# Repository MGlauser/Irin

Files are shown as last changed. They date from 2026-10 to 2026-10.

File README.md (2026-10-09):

# Irin

**The wakeful one: an always-on battery watcher for Home Assistant.**

Irin is an always-on battery monitor that clamps onto a battery's terminals and reports
**voltage, state of charge (SOC), charging activity and temperature** to
[Home Assistant](https://www.home-assistant.io/) over WiFi, with a tiny OLED readout on
the device itself.

The prototype watches the 12V accessory battery of a 2027 Subaru Uncharted GT (an EV whose
12V battery can run down in a couple of days of parking), but nothing in it is
car-specific. Change a few lines of configuration and it monitors **flooded lead-acid,
AGM, LiFePO4 or sodium-ion** batteries in **12V, 24V or 48V** systems: RVs and boats,
ham radio go-boxes and repeater power, solar and home backup banks, golf carts, stored
vehicles.

No cloud, no vehicle telematics, no OBD dongle: one ESP32 board on the battery, one
entry in your Home Assistant.

<p align="center">
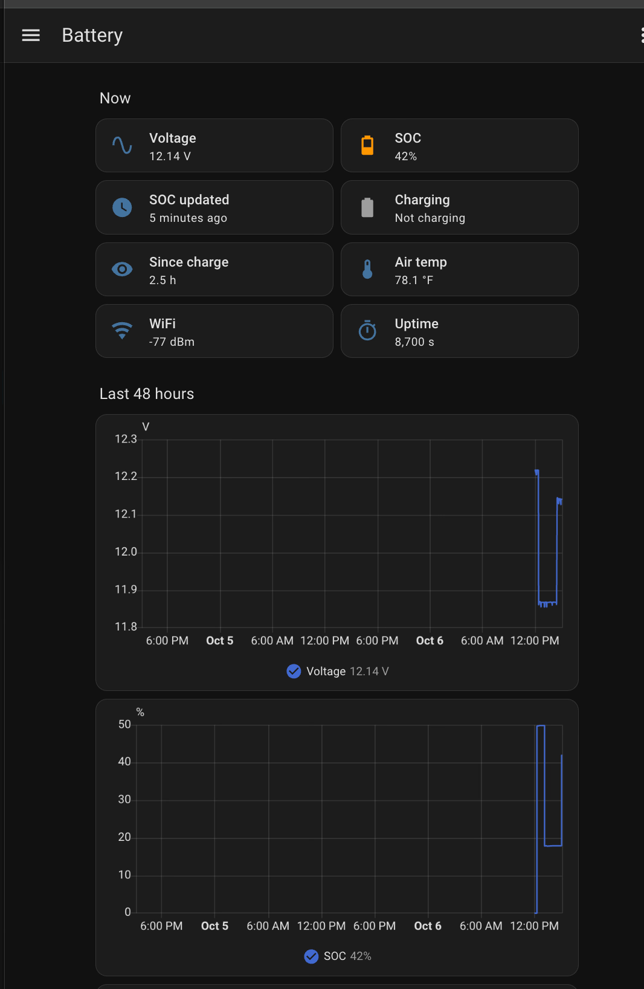
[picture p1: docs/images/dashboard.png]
Irin dashboard in Home Assistant: voltage, SOC, charging status and 48-hour history
  
</p>
<p align="center"><sub>The included dashboard on the bench prototype. SOC steps only
after a rest window (0% from an early reboot loop, then 50%, ~17% and 42% as the bench
supply was changed); voltage is charted continuously. And 42% is, of course, the
answer.</sub></p>

### The name

*Irin* (Aramaic עִירִין, *ʿirin*; singular *ʿir*) means "watchers", literally "the
wakeful ones": those who do not sleep. It is the word for the Watchers of the Book of
Enoch, whose first part (1 Enoch 1–36) is called *The Book of the Watchers* and survives
in Aramaic among the Dead Sea Scrolls. The same word appears in Daniel 4:13: "a watcher
and a holy one came down from heaven."

The name is meant in the sense of the *holy* Watchers, the ones who kept their post
(1 Enoch 20 names them: Uriel, Raphael, Raguel, Michael, Saraqael, Gabriel and Remiel),
not the fallen ones the book is better known for.

It is also the design in one word. Deep sleep was evaluated and rejected (on the
prototype it would buy about 2% more runway), so the monitor stays awake around the
clock, watching the battery so you don't have to.

---

## What it does

| | |
|---|---|
| **Voltage** | Measured every 30 s with a 16-bit ADC (0.7 mV resolution at 12V) and published continuously, never gated. Charts charging cycles in detail. |
| **State of charge** | Looked up from *resting* voltage, temperature-corrected, and only updated when the battery has truly rested (see below). Holds its last good value otherwise, with a "last updated" timestamp. |
| **Charging** | On/off, detected from voltage with hysteresis, plus *Time Since Charging*. Shows whether the charging source (alternator, DC-DC converter, solar, shore power) is actually doing its job. |
| **Away report** | While Home Assistant is unreachable (the car is away from home WiFi, or HA is down), the device keeps a summary: lowest voltage, lowest SOC, time below the alert level, charging time and events. Published when it reconnects, e.g. *"3.2 d: SOC min 46%, 4.0 h below 50%, 6 charges"*. Gaps under 30 minutes are ignored. |
| **Temperature / humidity** | DHT22 sensor, used for the SOC temperature correction. |
| **On-device display** | Voltage, SOC, temperature and rest/charging status on a 72×40 OLED. Blanks after 2 minutes to prevent burn-in; the BOOT button wakes it. Stays lit while charging. |
| **Home Assistant** | Native ESPHome integration (no MQTT broker), a ready-made dashboard, and history for long-term battery-health trends. Alerts are ordinary HA automations. |

It draws about **10 mA at 12V** on WiFi, and about **40 mA** while out of WiFi range with
its fallback network up (see [Fallback WiFi network](#fallback-wifi-network-and-its-power-cost)).

### Why SOC needs a "rest gate"

A battery's voltage only tells you its state of charge when it has been sitting
unloaded and uncharged for a while. During and after charging it reads high (surface
charge), so a naive voltage-to-SOC lookup reports 100% on a battery that may be
failing, and a low-battery alert fires late or never.

So SOC is recomputed only after the voltage has stayed below the charging threshold for
**30 minutes** *and* has been stable (within 5 mV per 5 minutes) for **15 minutes**.
Voltage itself is never gated: you always see the raw trace.

---

## Hardware

| Part | Notes |
|---|---|
| **01Space ESP32-C3-0.42LCD** ("ESP32-C3 SuperMini 0.42 OLED") | ESP32-C3 with a built-in 72×40 SSD1306 OLED. I2C on SDA=GPIO5 / SCL=GPIO6 (verified). |
| **ADS1115** 16-bit ADC module (e.g. HiLetgo) | I2C at 0x48 (ADDR→GND), powered from 3.3V. Battery on A0 through the divider. |
| **Voltage divider** R1/R2, 1% metal film, same series | 47k / 10k for 12V systems (see the voltage table for 24/48V). |
| **C1**, 2 nF across R2 | 2× 1000 pF mica in parallel (low leakage). |
| **MP1584EN** buck module, set to 5.0V | Feeds the board's 5V pin. 12V systems only; see 24/48V below. |
| **DHT22 / AM2302** + 3-pin JST-XH (J2) | Best outside the enclosure (cable ≤1 m at 3.3V); inside works, reading a few °C warm, which errs toward an early alert. |
| **Fuse** at the battery positive terminal | 5 A, DC-rated for the system voltage. Protects the wiring, not the 10 mA load. |
| **TVS diode** D1 | P6KE18A for 12V. Fitted as standard: it clamps switching transients, and a reversed hookup forward-biases it and blows the fuse. |
| **Enclosure** | 3D printed, PETG or ASA. |

- Full bill of materials, wiring and divider math: [`PARTS.md`](PARTS.md).
- Schematic: [`hardware/`](hardware/) (KiCad 10), PDF preview in
  [`hardware/preview.pdf`](hardware/preview.pdf).
- Breadboard layout for a 400-point board: open
  [`hardware/breadboard/breadboard.html`](hardware/breadboard/breadboard.html) in a
  browser. It is generated and checked against the schematic's netlist by
  `make_breadboard.py`.

### The one wiring rule that matters

**R2 and C1 must return to the ADS1115's own GND pin, and that ground must meet power
ground at exactly one point.** If the divider and the ADC sit on different ground paths,
the supply current's voltage drop appears in series with the measurement and gets
multiplied by the divider ratio. On the prototype, 15 mV of ground drop between two
breadboard rails became an 86 mV error at the battery, and it drifted.
This applies to wired builds. On the PCB, the solid GND plane does the same job and R2/C1
connect to it directly.

---

## Build and install

### 1. Bench build
1. Set the buck module to **5.0V** before connecting it to anything.
2. Build the circuit (breadboard first is a good idea; see the layout above).
3. Power from a bench supply. Check that the OLED lights up and both I2C devices appear
   in the ESPHome log (0x3C and 0x48).

### 2. Firmware (ESPHome)
The firmware is a single ESPHome config: [`esphome/irin.yaml`](esphome/irin.yaml).

**With the Home Assistant ESPHome add-on (Device Builder):**
1. Run `python3 esphome/www/build_www.py` (needs ESPHome installed; it writes
   `esphome/irin_www.js`, the status page script), then copy the YAML and `irin_www.js`
   into `/config/esphome/`. The script isn't in the repo because it is mostly ESPHome's
   own page code.
2. Add the keys from [`esphome/secrets.yaml.example`](esphome/secrets.yaml.example) to
   the add-on's `secrets.yaml` (Secrets button in the add-on).
3. Plug the ESP32 into the HA host by USB, then **Install**. Later updates go over WiFi.

**Or with the ESPHome command line:** copy `secrets.yaml.example` to `secrets.yaml`, fill
it in, and run `esphome run irin.yaml`.

Change `device_name` and `friendly_name` at the top of the YAML for each monitor you
build; entity IDs in HA follow `friendly_name`. The files in this repository are the
prototype's own configuration, named "Uncharted 12V", so the HA examples use entity IDs
like `sensor.uncharted_12v_battery_voltage`. If your `friendly_name` is "RV House", for
example, replace `uncharted_12v` with `rv_house` throughout `ha_config/`.

### 3. Calibrate (two-point)
Every divider is different, so calibrate against a good meter:
1. In the YAML, comment out the `calibrate_linear` block and install. *Battery Voltage*
   now shows the raw voltage at A0 (about 2 V on a 12V system).
2. Set a bench supply near the **bottom** of your range (11.50 V for 12V) and measure it
   **at the board** with a DVM. Note the true voltage and the raw reading.
3. Repeat near the **top** of your charging range (15.00 V for 12V).
4. Enter both pairs as `raw -> true`, uncomment, and reinstall:
   ```yaml
   - calibrate_linear:
       - 2.00320 -> 11.500
       - 2.61497 -> 15.000
   ```
5. Verify at your SOC alert point (e.g. 12.22 V) and at the maximum (16.00 V). Expect
   ±0.01 V.

The fitted slope should land close to your measured (R1+R2)/R2. If it is off by more than
a few tenths of a percent, suspect the ground wiring (see above) before the resistors.

### 4. Home Assistant
1. Settings → Devices & services: the device appears under **Discovered**. Add it (the
   encryption key is `uncharted_api_key` from your secrets).
2. Check the entity IDs. **Gotcha:** if the device is assigned to an area, HA may prefix
   new entity IDs with it (`sensor.garage_…`). Rename them, or edit the dashboard to
   match.
3. Dashboard: create a new dashboard, open the **Raw configuration editor**, and paste
   [`ha_config/dashboard.yaml`](ha_config/dashboard.yaml). For a
   single card on an existing dashboard, use
   [`ha_config/dashboard_card.yaml`](ha_config/dashboard_card.yaml).
4. Alerts: draft automations are in [`ha_config/`](ha_config/) (low SOC, charging
   stalled, device offline). Tune thresholds against a week or two of your own data
   before relying on them.

### 5. Install on the battery
- Ring terminals directly on the battery posts, fuse within ~15 cm (6") of the positive
  terminal. No splicing into vehicle harnesses.
- **If the battery has a current sensor clamped on its negative post** (many modern
  vehicles do), connect the monitor's ground on the chassis side of the sensor, so the
  vehicle still accounts for the monitor's current.
- Temperature sensor outside the enclosure near the battery if you can; inside the box is acceptable.
- Check the WiFi signal tile in HA at the final location before closing everything up.
  Below about −80 dBm, expect dropouts.

---

## Customizing

Everything you need to change is in the `substitutions:` block at the top of
[`esphome/irin.yaml`](esphome/irin.yaml), plus the divider
resistors and calibration for other system voltages.

| Setting | What it does | 12V flooded default |
|---|---|---|
| `soc_table_v` / `soc_table_pct` | Resting voltage → SOC lookup at 25 °C, ascending, same length | flooded table below |
| `charge_on_threshold` | Above this: charging | 12.90 V |
| `charge_off_threshold` | Below this: resting (the rest gate starts counting) | 12.80 V |
| `rest_required_sec` | Time below `charge_off_threshold` before SOC updates | 1800 s |
| `stable_required_sec` | Time the voltage must also be stable | 900 s |
| `slope_tolerance` | Allowed drift per 5-minute tick to count as stable | 0.005 V |
| `temp_coeff` | Resting-voltage temperature coefficient, V/°C, for the whole battery | 0.004 |
| `display_wake_ms` | How long the OLED stays lit | 120000 |
| `ap_ssid` | Name of the fallback WiFi network (see below). Don't name the vehicle: it broadcasts wherever you park | irin-Sunny |
| `soc_alert_pct` | SOC alert level, used for the away report's "time below alert" (match your HA automation) | 50 |
| `away_min_sec` | Shortest HA outage that counts as "away" and replaces the last report | 1800 s |

**Rule for the charging thresholds:** `charge_off_threshold` must sit **above** the
battery's full resting voltage (otherwise a full, idle battery looks like it is
charging), and **below** the lowest charging voltage you expect. Put
`charge_on_threshold` about 0.1 V higher (per 12V) for hysteresis.

### Fallback WiFi network (and its power cost)

When the device can't reach its WiFi for 90 seconds, it starts its own password-protected
network (`ap_ssid`). This is how you recover after changing your WiFi password without
re-flashing:

1. Join the fallback network from a phone, using `uncharted_fallback_password` from your secrets.
2. The setup page opens (or browse to `http://192.168.4.1`). Pick your network and enter
   the new password. The device saves it and reconnects.
3. **Then update `wifi_password` in your secrets before the next firmware install.** A
   password saved this way only applies to the firmware that is running; any install with
   a changed configuration goes back to the password in the YAML.

**Status page.** The device also serves a small status page: voltage, SOC, temperature,
charging and the away report. When the device is out of WiFi range, join the fallback
network and open `http://192.168.4.1`. On your home network, use
`http://<device_name>.local` (e.g. `http://uncharted-batt.local`). Log in as `irin`, with
the fallback password. Useful when the battery is in a sealed box and the OLED is out of
reach. While the fallback network is up, the setup page is still what your phone's
network-login popup shows. If you need it in a browser, open any other address on the
device, or tap **WiFi Setup** on the status page, just above OTA Update. That link
appears only while the fallback network is up, because that is the only time the setup
page exists. It comes from `esphome/irin_www.js`, which is ESPHome's own status page
script with the link added; after upgrading ESPHome, regenerate it with
`python3 esphome/www/build_www.py` (using the ESPHome install that builds the firmware) and
copy it next to the YAML. Don't want the link? Replace `js_include` and `js_url` with
`local: true` and drop the file.

For a *planned* password change you don't need the fallback network at all: list both
passwords under `wifi: networks:` (same SSID), install over WiFi while the old one still
works, then change the router.

**The cost: about 40 mA instead of 10 mA, but only while out of WiFi range.** A device
that can't find its network keeps the radio on, searching and broadcasting. On WiFi at
home there is no extra draw. Measured on the prototype at 12V. The extra 30 mA is about
0.7 Ah a day, around 3% of the capacity between full and the 50% alert on a 50 Ah
battery: for a car parked away from home, a few hours less warning out of several days. Daily trips cost about 0.25 Ah, which the drive
home replaces.

**To turn it off**, for example on a battery bank that spends long periods out of range,
or if you'd rather not broadcast a network: delete the `ap:` block under `wifi:` and the
`captive_portal:` line, then install. The status page then only works on your home
network. To remove it as well, delete the `web_server:` block and the
`web_server: {sorting_group_id: ...}` lines. Out-of-range draw then falls to an estimated 20-30 mA
(not measured), not to 10 mA, because the radio keeps searching. The trade-offs:
- Recovering from a WiFi password change needs the planned method above, or a USB flash.
- `wifi: reboot_timeout: 60min` becomes active (ESPHome only uses it when there is no
  fallback network): the device reboots after an hour without WiFi as a recovery
  backstop. The away report survives it (kept in flash) and a full SOC rest window fits
  between reboots, but the clock comes from Home Assistant, so after such a reboot,
  charging while out of range isn't timestamped and *Time Since Charging* reads high
  until the device is back home.

### Battery chemistry (12V)

> Published voltage tables vary by manufacturer by ±0.05 V or more. If your battery's
> datasheet gives a resting-voltage curve, use it. The tables below are typical values:
> good starting points, not gospel.

#### Flooded lead-acid (default)
```yaml
soc_table_v:   "11.60, 11.75, 11.90, 12.02, 12.12, 12.22, 12.30, 12.38, 12.48, 12.58, 12.70"
soc_table_pct: "    0,    10,    20,    30,    40,    50,    60,    70,    80,    90,   100"
charge_on_threshold:  "12.90"
charge_off_threshold: "12.80"
temp_coeff: "0.004"
```
Alert at **50%**: lead-acid cycle life drops sharply below 50% depth of discharge, and a
partially discharged flooded battery sulfates. The temperature coefficient is the
battery's *open-circuit* drift (~0.7 mV/°C per cell), **not** the 3-5 mV/°C/cell charger
compensation figure. Using the charger figure over-corrects cold readings and suppresses
winter alerts.

#### AGM (and gel, as a starting point)
```yaml
soc_table_v:   "11.60, 11.80, 11.95, 12.10, 12.25, 12.35, 12.45, 12.55, 12.65, 12.75, 12.85"
soc_table_pct: "    0,    10,    20,    30,    40,    50,    60,    70,    80,    90,   100"
charge_on_threshold:  "13.10"
charge_off_threshold: "13.00"
temp_coeff: "0.004"
```
AGM rests 0.10-0.15 V higher than flooded. **Using the wrong table is the classic
mistake:** an AGM table on a flooded battery reads high and fires the 50% alert at
roughly 35-40% actual SOC. Check the battery label. Alert at 50%.

#### LiFePO4 (LFP, 4S "12.8V")
```yaml
soc_table_v:   "12.00, 12.90, 13.07, 13.13, 13.17, 13.20, 13.22, 13.25, 13.28, 13.30, 13.40"
soc_table_pct: "    0,    10,    20,    30,    40,    50,    60,    70,    80,    90,   100"
charge_on_threshold:  "13.60"
charge_off_threshold: "13.50"
temp_coeff: "0"
```
**Read this before trusting LFP SOC.** LiFePO4's resting voltage is almost flat: 20% to
90% spans only about 0.23 V, roughly 3 mV per percent, and the curve shifts with recent
charge/discharge history and temperature. Voltage-based SOC is therefore only
trustworthy near the ends of the curve (below ~20% and at full), and can be off by
10-20 points in the middle. Treat it as a **low / OK / full** indicator, and set the
alert near **20%**, where the curve bends and voltage becomes informative. LFP tolerates
deep cycling far better than lead-acid anyway. Accurate mid-range LFP SOC needs current
measurement (a shunt and coulomb counting), which this design does not do yet. The
ADS1115 has spare inputs for exactly that; see *Ideas* below.

Also: a pack's BMS may disconnect the output at low charge. If the monitor is powered
from the BMS-protected output, it goes dark exactly when the battery is lowest.

#### Sodium-ion (Na-ion, 12V packs)
Sodium-ion cells have a **sloped** discharge curve, much more like lead-acid than LFP,
so voltage-based SOC works well. Cell chemistries and pack configurations still vary
between manufacturers, so there is no universal table. Build yours from the pack's
datasheet discharge curve, or measure it (procedure below). Start with:
```yaml
temp_coeff: "0"          # until you have characterized it
charge_off_threshold:    # just above the pack's full *resting* voltage
charge_on_threshold:     # charge_off_threshold + 0.1
```
Check the pack's maximum charge voltage. The 12V divider is designed for 16 V and is
safe to about 20 V, so a pack that charges above ~15.5 V should get a slightly higher
ratio, plus recalibration.

#### Measuring your own SOC table (any chemistry)
1. Fully charge the battery, then let it rest for at least 2 hours (lead-acid: overnight).
   Record the voltage as 100%.
2. Discharge 10% of rated capacity at a gentle rate (≤ C/20) with a load and an Ah meter.
3. Rest at least 1 hour (lead-acid: 4+ hours), then record the voltage at that SOC.
4. Repeat down to your lowest acceptable level. Do this at around 25 °C.

### System voltage: 24V and 48V

The measurement chain works the same at any voltage. Four parts change in hardware,
and the per-12V numbers scale in firmware.

| | **12V** | **24V** | **48V** |
|---|---|---|---|
| Design maximum (charging + margin) | 16 V | 32 V | 64 V |
| Divider R1 / R2 | 47k / 10k | 100k / 10k | 220k / 10k |
| Ratio | 5.7 : 1 | 11 : 1 | 23 : 1 |
| A0 at design maximum | 2.80 V | 2.91 V | 2.78 V |
| Input reaches the ADS1115's 3.6 V abs. max at | 20.6 V | 39.6 V | 82.8 V |
| Resolution at the battery | 0.7 mV | 1.4 mV | 2.9 mV |
| Buck converter input rating | MP1584EN (28 V max) OK | **≥ 60 V** (24V lead-acid charges to ~29 V; the MP1584 is **not** OK) | **≥ 100 V** |
| TVS | P6KE18A | P6KE36A (30.8 V standoff: skip it if you equalize above ~30.5 V) | SMBJ60A (60 V standoff): LFP 16S and lead-acid without equalization |
| Fuse | 32 V DC automotive blade OK | 32 V DC blade OK | **58 V DC-rated** blade fuse; standard automotive blades are only 32 V |
| Calibration points | 11.5 V / 15.0 V | 23 V / 30 V | 46 V / 60 V |

Choosing parts for other cases:
- **Divider:** keep A0 at or below ~2.9 V at your design maximum, so the ADS1115 (powered
  at 3.3V) has margin to its 3.6 V absolute maximum. Keep R2 around 10k so the source
  impedance stays low.
- **TVS:** its standoff voltage must be at or above your maximum charging voltage, and its
  clamping voltage must be below the buck's maximum input.
- **Buck:** check the converter chip's datasheet input rating, not the seller's headline
  number.

**Firmware for 24V / 48V:** multiply every per-battery voltage by 2 (24V) or 4 (48V):
`soc_table_v`, both charging thresholds, `slope_tolerance` and `temp_coeff`. Lead-acid
and LFP tables scale exactly with cell count (a 12V lead-acid battery is 6 cells, 24V
is 12, 48V is 24; 12V LFP is 4S, 24V is 8S, 48V is 16S). Then calibrate as above. The
display and HA entities need no changes.

---

## Things that will bite you

- **SOC is only valid at rest.** Do not shorten the rest gate to get more frequent
  updates; surface charge reads high, which inflates SOC and fires the low alert late.
  SOC is often hours old. That's what the *SOC Last Updated* timestamp is for.
- **Match the SOC table to the chemistry** (see above).
- **Analog ground** (see *The one wiring rule that matters*).
- **The ADS1115 must be powered from 3.3V, not 5V.** The divider ratio protects a 3.3V
  part; at 5V the input ceiling and the math both change.
- **Mislabeled resistors exist.** Measure R1 and R2 before soldering. The prototype got a
  "100k" from a resistor strip that measured 100 Ω.
- **WiFi is required.** ESPHome needs it. The device keeps measuring and updating its
  display without HA (and won't reboot just because HA is down), but nothing reaches
  your phone; the away report fills in the summary on reconnect, but not the minute-by-
  minute history, and can't alert you while away. Remote sites without WiFi would need a
  different radio (LoRa, Meshtastic, cellular).

## Ideas / roadmap

- Current shunt on the ADS1115's spare A2/A3 inputs (differential mode), or an INA226,
  for coulomb counting: accurate LFP SOC, real Ah in and out.
- Second divider on A1 for dual-bank systems (an RV's starter and house batteries).
- ESPHome *packages*: a shared base config plus a short per-install file with just
  chemistry and voltage settings.
- A small PCB, possibly as a club kit.

## Repository layout

| Path | Contents | License |
|---|---|---|
| `esphome/` | ESPHome firmware config, secrets template, status page script (`www/` builds it) | MIT |
| `ha_config/` | HA dashboard, draft automations, config snippets | MIT |
| `hardware/` | KiCad schematic, PCB placement, custom footprints, netlist, PDF preview | CERN-OHL-P-2.0 |
| `hardware/breadboard/` | Breadboard layout generator (Python) and its HTML output | MIT |
| `docs/images/` | Screenshots | MIT |
| `PARTS.md` | Bill of materials, wiring, divider math | MIT |
| `CLAUDE.md` | Full design record: rationale, measurements, rejected options, bench log. Written as context for the AI assistant used to develop the project, and the most detailed technical reference here. | MIT |

## Status

Bench-verified (October 2026): calibration within ±0.01 V from 11.5 to 16 V, the rest
gate and temperature correction, the charging-detection hysteresis, the display timeout,
and Home Assistant integration. Next: perfboard build, enclosure, in-vehicle data, then
tuned alerts.

## Versioning

The firmware carries a version, `irin_version` at the top of
[`esphome/irin.yaml`](esphome/irin.yaml) (currently **0.3.0**). It shows in two places:

- **Home Assistant device page** (Settings → Devices → your device): the firmware line
  shows the ESPHome version and `mglauser.irin` plus the Irin version.
- **Firmware** sensor, in the Diagnostics group of the status page and in HA, e.g.
  *"Irin 0.3.0, ESPHome 2026.9.1, built 2026-10-07 13:20:00 -0700"*. The build time
  changes on every install, so you can always tell whether an install took effect, even
  if nobody bumped the version.

**When reporting a problem, include the Firmware line.**

Rules for changes (semantic versioning, `MAJOR.MINOR.PATCH`):

| Change | Bump | Example |
|---|---|---|
| Fix that doesn't change what the device reports | PATCH | 0.3.0 → 0.3.1 |
| New feature or entity, changed behavior or default tunable | MINOR | 0.3.1 → 0.4.0 |
| Change that breaks existing installs (renamed entities, new required secret, new wiring) | MAJOR (MINOR while 0.x) | |

- Bump `irin_version` **in the same commit** as the YAML change, add a line under
  [Changelog](#changelog), and tag the commit: `git tag v0.3.1 && git push --tags`.
- Docs-only, dashboard-only, and hardware-file changes don't bump the firmware version.
- Still 0.x: a prototype that is still changing. **1.0.0** is planned for when the
  reference build is installed on the battery in its enclosure and the alerts are proven.

### Changelog

- **0.3.0** (2026-10-07). First versioned build. Away report, fallback network
  `irin-<car>` with a WiFi Setup link on the status page, readable uptime, rest gate
  requires a true 30 minutes of observed rest, Firmware sensor.

## License

- **Software** (firmware, HA configs, scripts, documentation): [MIT](LICENSE)
- **Hardware design files** in `hardware/` (except `hardware/breadboard/`):
  [CERN Open Hardware Licence v2, Permissive (CERN-OHL-P-2.0)](hardware/LICENSE)

Provided as-is. You are working on battery systems that can deliver very large currents.
Fuse at the battery, insulate everything, and know your vehicle's service precautions.

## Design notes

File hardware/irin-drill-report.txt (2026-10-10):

Drill report for irin.kicad_pcb
Created on 2026-10-10T12:10:41

Copper Layer Stackup:
    =============================================================
    L1 :  F.Cu                      front
    L2 :  B.Cu                      back

Drill file 'irin-PTH.drl' contains
    plated through holes:
    =============================================================
    T1  0.800mm  0.0315"  (10 holes))
    T2  0.950mm  0.0374"  (3 holes))
    T3  1.000mm  0.0394"  (34 holes))
    T4  1.200mm  0.0472"  (2 holes))
    T5  1.300mm  0.0512"  (2 holes))

    Total plated holes count 51

Drill file 'irin-NPTH.drl' contains
    unplated through holes:
    =============================================================
    T1  3.200mm  0.1260"  (4 holes))

    Total unplated holes count 4

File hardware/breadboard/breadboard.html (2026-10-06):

## Irin 12V battery monitor — breadboard (400-point, 30 columns)

Generated by make_breadboard.py and validated against irin.net: every net connected, no shorts, unused module pins isolated. Hover a jumper for its purpose.

### Parts

Ref | Part | Holes
U1 | U1 MP1584 | IN−=c11, IN−=c12, IN+=c14, IN+=c15, OUT−=h11, OUT−=h12, OUT+=h14, OUT+=h15
D1 | D1 P6KE18A (opt.) | T+ rail @5 ↔ T- rail @5 — K at T+ (band)
C3 | C3 0.1uF | T+ rail @8 ↔ T- rail @8
C2 | C2 100uF/35V | T+ rail @13 ↔ T- rail @13 — + at T+
U2 | U2 ESP32-C3 | GPIO3=c8, GPIO5=c6, GPIO6=c5, 3V3=h3, GND=h2, 5V=h1
J2 | remote DHT22 leads | DHT VCC=B+ rail @16, DHT DATA=b8, DHT GND=B- rail @16
U3 | U3 ADS1115 (0x48) | A3=j18, A2=j19, A1=j20, A0=j21, ALRT=j22, ADDR=j23, SDA=j24, SCL=j25, GND=j26, VDD=j27
R1 | R1 47k | c17 ↔ c21
R2 | R2 10k | d21 ↔ d25
C1 | C1 2x1000pF mica | e21 ↔ e25

### Jumpers

From | To | Purpose
T- rail @11 | a11 | buck IN− → GND
T+ rail @15 | a15 | buck IN+ ← 12V
j11 | B- rail @11 | buck OUT− → GND
i14 | i1 | 5V: buck OUT+ → ESP 5V
T- rail @10 | B- rail @10 | GND tie, top ↔ bottom rails
j2 | B- rail @2 | ESP GND
j3 | B+ rail @3 | ESP 3V3 → 3V3 rail
T+ rail @17 | a17 | 12V to divider top
a25 | h26 | divider GND → ADS GND strip
b21 | f21 | A0 node → ADS A0
a6 | f24 | GPIO5 → SDA
a5 | f25 | GPIO6 → SCL
g23 | g26 | ADDR → GND (0x48)
T- rail @26 | f26 | analog GND: single tie to power GND
i27 | B+ rail @29 | ADS VDD ← 3V3

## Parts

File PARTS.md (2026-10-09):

# Parts List — Irin battery monitor (12V prototype)

Enough parts for **three complete units** once the remaining items land.

---

## On hand / ordered

| Item | Qty | Notes |
|---|---|---|
| ESP32-C3 0.42" OLED board (01Space design) | 3 | |
| HiLetgo ADS1115 16-bit 4-ch ADC (B07VPFLSMX) | 3 | Ordered, $11.89. No Qwiic connector. |
| MP1584EN buck module, adjustable | 5 | Ordered, $8.69. Set to 5.0 V. |
| DHT22 / AM2302 | 2 | Ordered, $7.99. On J2; **inside the box for now** (2026-10-08) — see below. |
| 18 GA micro fuse holders, inline | 6 | Ordered, $8.99. Confirm fuses included. |
| PETG / ASA filament | — | On hand. Enclosure printed in-house. |

---

## Still to order

### Check stock — not on the Amazon order

| Item | Qty | Notes |
|---|---|---|
| TVS, 18 V breakdown | 3 | **P6KE18A** — 600 W DO-15. VRWM 15.3 V, VBR 17.1-18.9 V, Vc 25.2 V at 24 A. MP1584 abs max is 30 V. Standard on the PCB (also the reverse-polarity crowbar). Banded end (cathode) to the + rail. |
| Micro blade fuses, 5 A | 3 | If not included with the holders |

**Reverse-polarity Schottky: dropped by decision.** Owner-built, wired once — not a
failure mode worth a diode or the 0.4 V it costs.

TVS is a different case and is fitted as standard (2026-10-08): it handles inductive
switching transients, and a reversed hookup forward-biases it and blows the fuse, which
protects kits built by others.

Source: [20PCS P6KE18A, DO-15 axial, unidirectional, 600 W](https://www.amazon.com/dp/B0FRMDHL9Q)

> **Suffix matters:** `P6KE18A` is unidirectional, `P6KE18CA` is bidirectional. Use the
> **A** on a ground-referenced DC rail — it clamps lower and there is no negative
> excursion to suppress. Many Amazon listings and assortments default to CA.

*Qwiic cable dropped: soldering GPIO5/6/3V3/GND to header pins beats fabricating a
JST SH 1 mm pigtail.*

### Likely already in stock

| Item | Qty | Notes |
|---|---|---|
| 47k 1% metal film | 3 | Divider R1 (measure before fitting — a mislabeled strip bit once) |
| 10k 1% metal film | 3 | Divider R2 — same series as R1 |
| 4.7k-10k | 3 | DHT22 data pullup (bare 4-pin part only; 3-pin modules have it) |
| 0.1 µF ceramic | 3 | Buck input (C3) |
| 1000 pF mica | 6 | Two in parallel across R2 (C1 = 2 nF) |
| 100 µF / 35 V electrolytic | 3 | Buck input bulk |
| JST-XH 3-pin header + housing/crimps, 3-core cable (≤1 m) | 3 | J2 remote DHT22 lead |
| 2-pin screw terminal, 5.08 mm pitch (KF301-2P / Phoenix MKDS 1,5-2-5.08 class) | 3 | J1, 12 V leads (PCB rev B) |
| Perfboard, 18 AWG wire, ring terminals, cable glands, heat shrink | — | |

Net new spend: **~$25-30**.

---

## Divider

**47k / 10k = 5.7:1** (unit 1 measured 46.5k / 9.85k = 5.72:1; was 470k/100k). Sized against the ADS1115's VDD+0.3 = 3.6 V ceiling at
VDD = 3.3 V.

| Battery | At A0 |
|---|---|
| 12.22 V (50% SOC, flooded) | 2.14 V |
| 14.4 V (DC-DC on) | 2.52 V |
| 16.0 V (design max) | 2.80 V |
| — 3.6 V limit reached at — | 20.6 V |

PGA gain 1 (±4.096 V FSR) → 125 µV/LSB = 0.71 mV at the battery.

2 nF (2 x 1000 pF mica) across R2. 1% is fine — calibration cancels initial tolerance, and same-series
parts cancel most tempco in the ratio.

---

## Connections

**ADS1115** — Qwiic from the ESP32 (red 3.3 V, black GND, blue SDA, yellow SCL) to the
module. ADDR to GND = 0x48; OLED is 0x3C.

**Power** — 5 V into the board's 5V pin. Efficiency is irrelevant against the
vehicle's own parked draw, and this keeps onboard protection plus USB for flashing.

**DHT22** — data on **GPIO3**. 4.7-10k pullup if using the bare 4-pin part. ESPHome
`update_interval: 300s`; expect occasional NaN from WiFi interrupt jitter, which is
harmless at this timescale.

> **Decided (2026-10-05): DHT22 remote-mounted outside the enclosure**, on a 3-wire
> cable to board connector J2 (JST-XH 3-pin, 1=VCC 2=DATA 3=GND) through a cable gland.
> Removes the self-heating offset of the earlier inside-mount. At 3.3 V supply the
> AM2302 datasheet limits the cable to ~1 m.
>
> **For now (2026-10-08): inside the first PCB enclosure**, plugged into J2 and glued to
> the wall, so the box has a single cable entry (12 V). Reads a few degC warm; errs safe.

**Fuse** — the fuse protects the 18 GA harness against a chassis short, not the 150 mA
load. 5 A against 18 GA is correct; Micro2 blade fuses are scarce below 5 A anyway.

**Front end** —

```
Battery+ ──[5A fuse]──┬──[47k/10k divider]────> ADS1115 A0
                      ├──[TVS 18V]──┐   (standard)
                      └─────────────┴──> MP1584 ──> 5 V
Battery- ──────────────────────────────────────────> GND
```

Straight to the battery posts, not a downstream accessory circuit.

---

## Open items

- [ ] Qwiic connector populated on the board? Else GPIO5/6/3V3/GND direct.
- [ ] 12V battery location — under hood vs. rear drives enclosure temp rating and WiFi margin
- [x] Battery chemistry: flooded lead-acid, 50 Ah (confirmed 2026-10-05; not AGM)
- [ ] WiFi RSSI at the mounting location (ceramic chip antenna; a metal bay is worst case)
- [x] Temperature sensor: DHT22/AM2302 on J2, inside the box for now (DS18B20 not used)

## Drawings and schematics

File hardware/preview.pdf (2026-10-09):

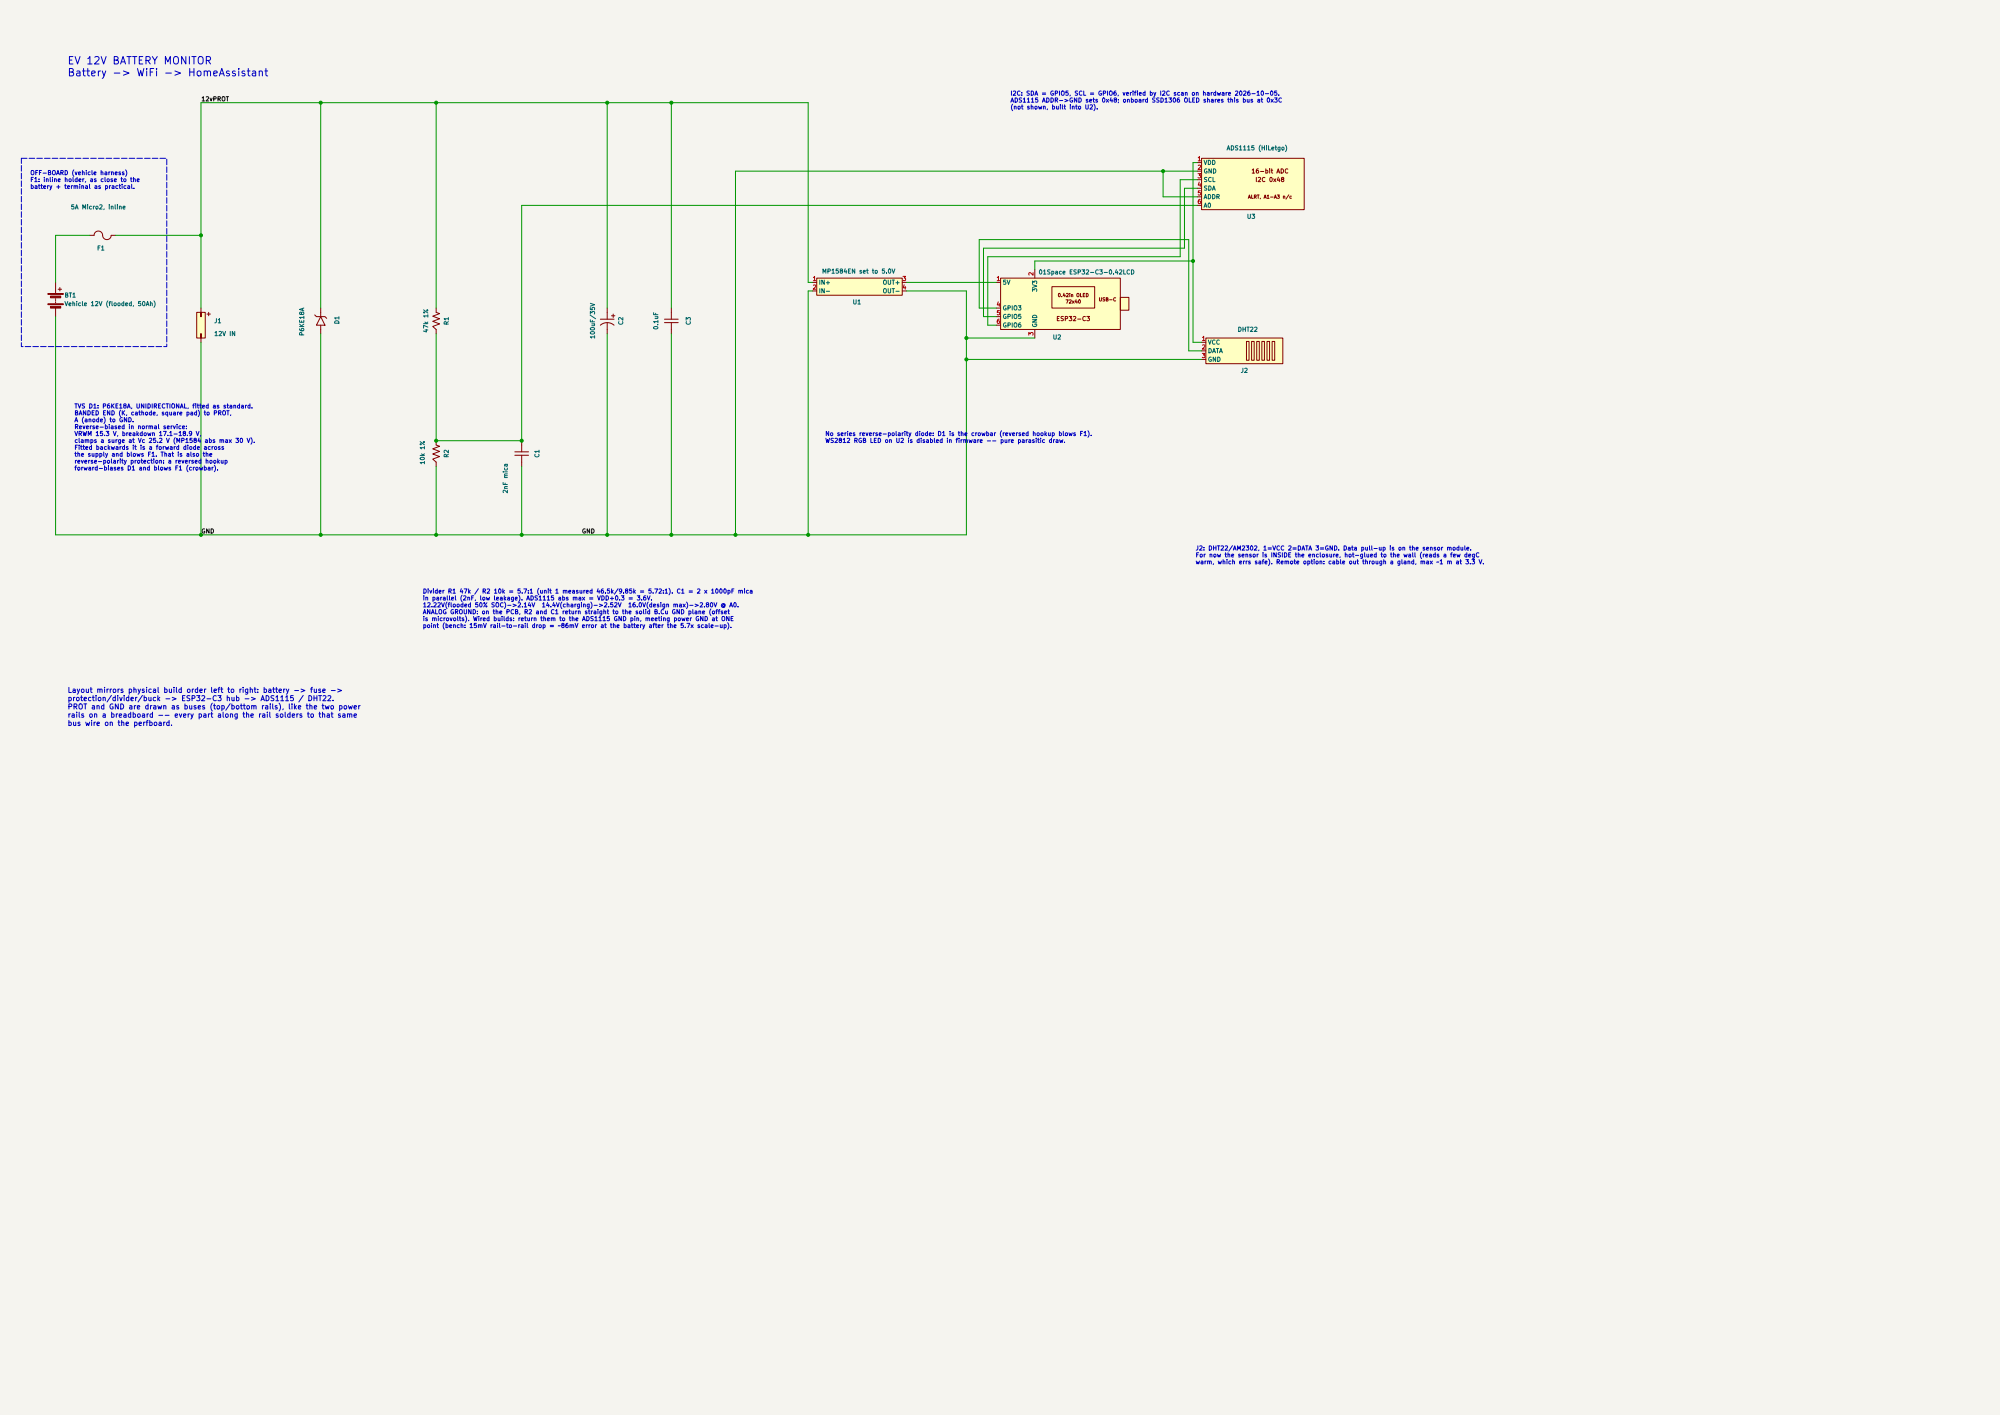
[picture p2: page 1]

I2C: SDA = GPIO5, SCL = GPIO6, verified by I2C scan on hardware 2026-10-05. ADS1115 ADDR->GND sets 0x48; onboard SSD1306 OLED shares this bus at 0x3C

forward-biases D1 and blows F1 (crowbar). OFF-BOARD (vehicle harness) F1: inline holder, as close to the battery + terminal as practical.

reverse-polarity protection: a reversed hookup

in parallel (2nF, low leakage). ADS1115 abs max = VDD+0.3 = 3.6V. 12.22V(flooded 50% SOC)->2.14V 14.4V(charging)->2.52V 16.0V(design max)->2.80V @ A0. ANALOG GROUND: on the PCB, R2 and C1 return straight to the solid B.Cu GND plane (offset

is microvolts). Wired builds: return them to the ADS1115 GND pin, meeting power GND at ONE
point (bench: 15mV rail-to-rail drop = ~86mV error at the battery after the 5.7x scale-up).

Layout mirrors physical build order left to right: battery -> fuse ->
protection/divider/buck -> ESP32-C3 hub -> ADS1115 / DHT22.
PROT and GND are drawn as buses (top/bottom rails), like the two power

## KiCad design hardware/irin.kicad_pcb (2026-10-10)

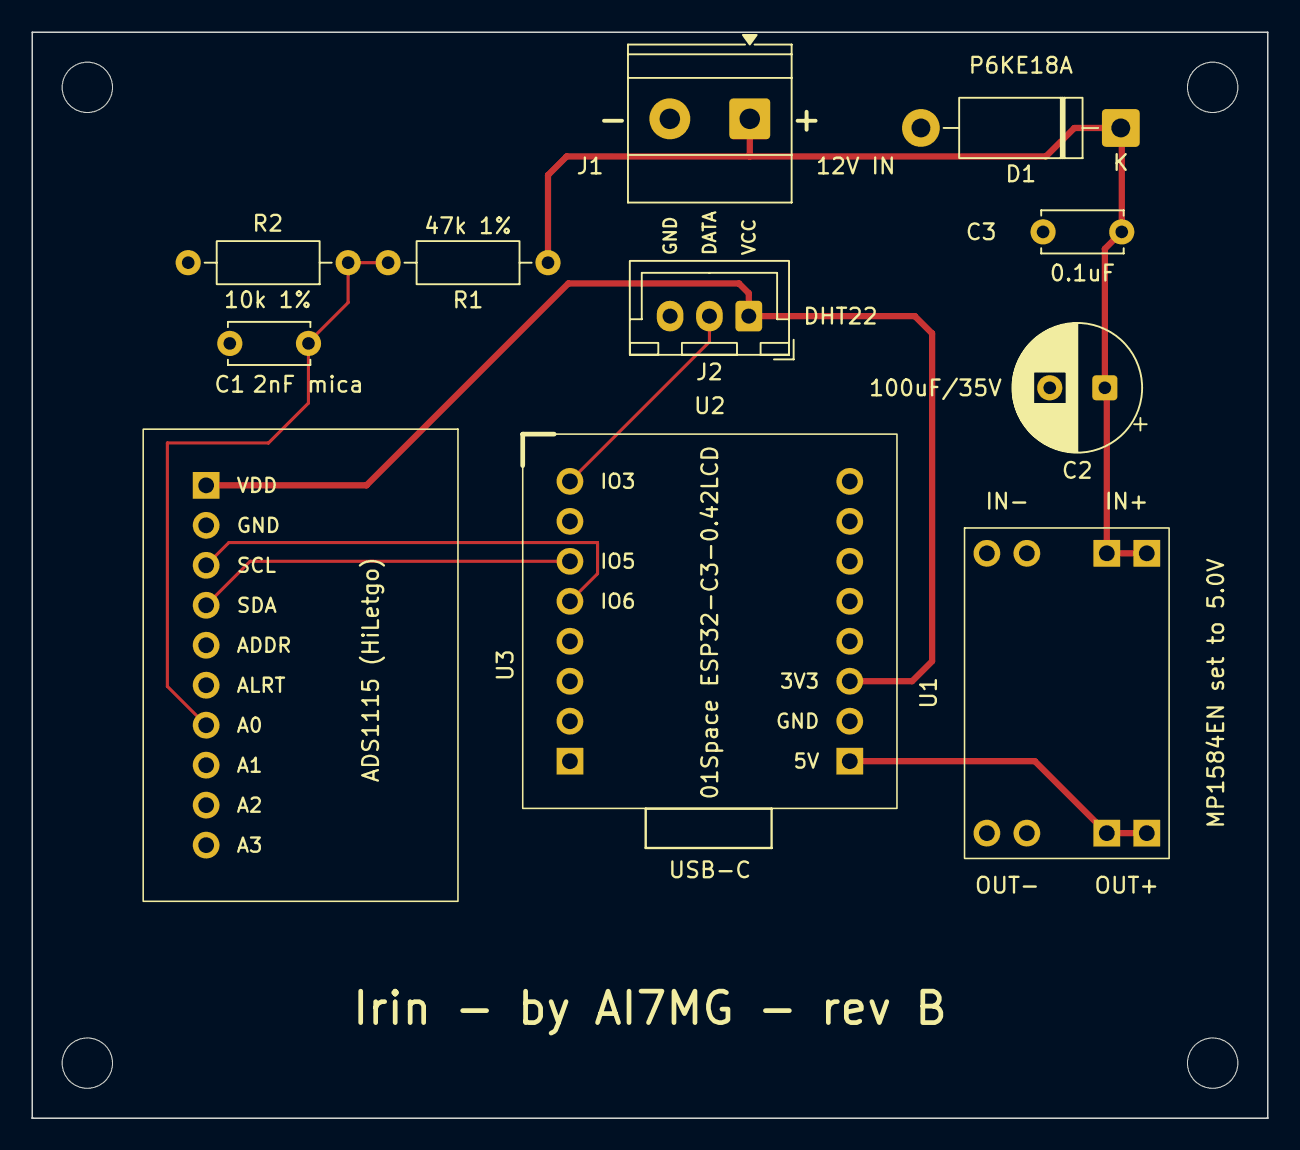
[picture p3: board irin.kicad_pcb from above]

Board: 2 copper layers, 78.5 x 69.0 mm, 15 parts (0 on the bottom side), 8 nets.

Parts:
C1: 2nF mica; C_Disc_D5.0mm_W2.5mm_P5.00mm
C2: 100uF/35V; CP_Radial_D8.0mm_P3.50mm
C3: 0.1uF; C_Disc_D5.0mm_W2.5mm_P5.00mm
D1: P6KE18A; D_DO-15_P12.70mm_Horizontal
H1, H2, H3, H4: MountingHole_3.2mm_M3
J1: 12V IN; TerminalBlock_Phoenix_MKDS-1,5-2-5.08_1x02_P5.08mm_Horizont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
J2: DHT22; JST_XH_B3B-XH-A_1x03_P2.50mm_Vertical
R1: 47k 1%; R_Axial_DIN0207_L6.3mm_D2.5mm_P10.16mm_Horizontal
R2: 10k 1%; R_Axial_DIN0207_L6.3mm_D2.5mm_P10.16mm_Horizontal
U1: MP1584EN set to 5.0V; MP1584EN_HW133_2x2Pad_P2.54mm_W7.62mm_L17.78mm
U2: 01Space ESP32-C3-0.42LCD; ESP32C3_042LCD_2x8_P2.54mm_W17.78mm
U3: ADS1115 (HiLetgo); ADS1115_HiLetgo_1x10_P2.54mm_W18mm_L28.3mm

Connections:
/12vPROT: C2.1 (+), C3.1, D1.1 (K), J1.1, R1.1, U1.1 (IN+)
/GND: C1.2, C2.2 (-), C3.2, D1.2 (A), J1.2, J2.3 (GND), R2.2, U1.2 (IN-), U1.4 (OUT-), U2.3 (GND), U3.2 (GND), U3.5 (ADDR)
unnamed: J2.2 (DATA), U2.4 (GPIO3)
unnamed: J2.1 (VCC), U2.2 (3V3), U3.1 (VDD)
unnamed: U1.3 (OUT+), U2.1 (5V)
unnamed: U2.5 (GPIO5), U3.4 (SDA)
unnamed: U2.6 (GPIO6), U3.3 (SCL)
unnamed: C1.1, R1.2, R2.1, U3.6 (A0)

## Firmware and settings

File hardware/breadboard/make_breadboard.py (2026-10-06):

#!/usr/bin/env python3
# SPDX-License-Identifier: MIT
"""
Breadboard layout for Irin, the 12V battery monitor (400-point half-size board: 30 columns, rows a-j, two rails each side).

Placements are hand-chosen; module pin positions come from the project's
footprints (Irin.pretty) rotated onto the 0.1" grid. The layout is
validated against the KiCad netlist before anything is drawn: every net must
be exactly one connected group, no two nets may short, and unused module pins
must sit in otherwise-empty strips.

    python3 make_breadboard.py            # validate + write breadboard.html
"""
import html
import re
import sys
from pathlib import Path

HERE = Path(__file__).resolve().parent
NETLIST = HERE.parent / 'irin.net'
OUT = HERE / 'breadboard.html'

NCOLS = 30
TOP_ROWS, BOT_ROWS = 'abcde', 'fghij'
# Rail assignment
RAILS = {'T+': '12V PROT', 'T-': 'GND', 'B+': '3V3', 'B-': 'GND'}

# ---------------------------------------------------------------- placement
# hole = (row, col) with row in a-j or a rail name.
parts = {}      # ref -> dict(kind, pins={pin: hole}, label, ...)


def module(ref, label, pins, body, color):
    """pins: {pin: (row, col, name)}; body: (col0, row0, col1, row1) in grid units."""
    parts[ref] = dict(kind='module', label=label, body=body, color=color,
                      pins={p: (r, c) for p, (r, c, _) in pins.items()},
                      names={p: n for p, (r, c, n) in pins.items()})


def two_lead(ref, label, a, b, color, polar=None):
    parts[ref] = dict(kind='lead', label=label, color=color, polar=polar,
                      pins={'1': a, '2': b})


# Off-board: bench supply (later the battery) through the inline fuse holder.
parts['J1'] = dict(kind='off', pins={'2': ('T-', 1)})
parts['F1'] = dict(kind='off', pins={'2': ('T+', 1)})

# MP1584 (HW-133) straddling the channel, input edge up, right of the ESP32.
# Footprint: IN- x=-5.08,-2.54 / IN+ x=+2.54,+5.08 at y=-8.89; OUT same x at y=+8.89.
module('U1', 'U1 MP1584', {
    '2': ('c', 11, 'IN−'), '2b': ('c', 12, 'IN−'),
    '1': ('c', 14, 'IN+'), '1b': ('c', 15, 'IN+'),
    '4': ('h', 11, 'OUT−'), '4b': ('h', 12, 'OUT−'),
    '3': ('h', 14, 'OUT+'), '3b': ('h', 15, 'OUT+'),
}, body=(10.0, 'c-', 16.0, 'h+'), color='#1d4ed8')

# Input protection / bulk, straight across the top rail pair.
two_lead('D1', 'D1 P6KE18A (opt.)', ('T+', 5), ('T-', 5), '#555', polar='K at T+ (band)')
two_lead('C3', 'C3 0.1uF', ('T+', 8), ('T-', 8), '#d97706')
two_lead('C2', 'C2 100uF/35V', ('T+', 13), ('T-', 13), '#2563eb', polar='+ at T+')

# ESP32-C3-0.42LCD straddling the channel at the left end, power pins
# bottom-left so the USB-C end (assumed to be the 5V/GND/3V3 end) hangs off
# the left edge of the breadboard for flashing. GPIO side faces up.
# Footprint left column (x=0), y=0..17.78: 4(GPIO3) 7 5(GPIO5) 6(GPIO6) 8 9 10 11
# right column (x=17.78):                12 13 14 15 16 2(3V3) 3(GND) 1(5V)
# Rotation (x,y) -> (col = c0 + 7 - y/2.54, row = top if x==0 else bottom)
C0 = 1
left = ['4', '7', '5', '6', '8', '9', '10', '11']
right = ['12', '13', '14', '15', '16', '2', '3', '1']
names = {'4': 'GPIO3', '5': 'GPIO5', '6': 'GPIO6', '1': '5V', '2': '3V3', '3': 'GND'}
esp = {}
for k, p in enumerate(left):
    esp[p] = ('c', C0 + 7 - k, names.get(p, '—'))
for k, p in enumerate(right):
    esp[p] = ('h', C0 + 7 - k, names.get(p, '—'))
module('U2', 'U2 ESP32-C3', esp, body=(C0 - 1.6, 'c-', C0 + 7.8, 'h+'), color='#111827')

# J2 / remote DHT22: no header on the breadboard. The sensor cable's three
# leads land directly: VCC in the 3V3 rail, GND in the GND rail, DATA in the
# GPIO3 column.
parts['J2'] = dict(kind='cable', label='remote DHT22 leads', color='#7c3aed',
                   pins={'1': ('B+', 16), '2': ('b', 8), '3': ('B-', 16)},
                   names={'1': 'DHT VCC', '2': 'DHT DATA', '3': 'DHT GND'})

# ADS1115 in the bottom half, pins in row j, rotated 180° so the board hangs
# out over the bottom rails. Silkscreen order (pins down) VDD GND SCL SDA ADDR
# ALRT A0 A1 A2 A3 reads reversed left→right from this side.
ads_order = [('10', 'A3'), ('9', 'A2'), ('8', 'A1'), ('6', 'A0'), ('7', 'ALRT'),
             ('5', 'ADDR'), ('4', 'SDA'), ('3', 'SCL'), ('2', 'GND'), ('1', 'VDD')]
ADS0 = 18
module('U3', 'U3 ADS1115 (0x48)',
       {p: ('j', ADS0 + k, n) for k, (p, n) in enumerate(ads_order)},
       body=(ADS0 - 0.6, 'j-', ADS0 + 9.6, 'B-+'), color='#0f766e')

# Divider in the top half, above the ADS1115: 12 V strip 17 -> R1 -> node
# strip 21 -> R2 / C1 -> strip 25. Node drops straight across the channel to A0.
# Strip 25 returns to the ADS1115 GND strip (26), NOT to a rail: the divider and
# ADC share one analog ground that meets power ground at a single jumper. Tying
# them to different rails put a ~15 mV, load-dependent rail-to-rail drop in series
# with A0 (~86 mV at the battery after the 5.7:1 scale-up). Found 2026-10-06.
two_lead('R1', 'R1 47k', ('c', 17), ('c', 21), '#b45309')
two_lead('R2', 'R2 10k', ('d', 21), ('d', 25), '#b45309')
two_lead('C1', 'C1 2x1000pF mica', ('e', 21), ('e', 25), '#d97706')

# ---------------------------------------------------------------- jumpers
# (from, to, colour, net label)
RED, BLK, ORG, YEL, BLU, GRN, WHT, VIO = ('#dc2626', '#1f2937', '#ea580c', '#ca8a04',
                                          '#2563eb', '#16a34a', '#9ca3af', '#7c3aed')
jumpers = [
    (('T-', 11), ('a', 11), BLK, 'buck IN− → GND'),
    (('T+', 15), ('a', 15), RED, 'buck IN+ ← 12V'),
    (('j', 11), ('B-', 11), BLK, 'buck OUT− → GND'),
    (('i', 14), ('i', 1), ORG, '5V: buck OUT+ → ESP 5V'),
    (('T-', 10), ('B-', 10), BLK, 'GND tie, top ↔ bottom rails'),
    (('j', 2), ('B-', 2), BLK, 'ESP GND'),
    (('j', 3), ('B+', 3), RED, 'ESP 3V3 → 3V3 rail'),
    (('T+', 17), ('a', 17), RED, '12V to divider top'),
    (('a', 25), ('h', 26), BLK, 'divider GND → ADS GND strip'),
    (('b', 21), ('f', 21), GRN, 'A0 node → ADS A0'),
    (('a', 6), ('f', 24), BLU, 'GPIO5 → SDA'),
    (('a', 5), ('f', 25), YEL, 'GPIO6 → SCL'),
    (('g', 23), ('g', 26), BLK, 'ADDR → GND (0x48)'),
    (('T-', 26), ('f', 26), BLK, 'analog GND: single tie to power GND'),
    (('i', 27), ('B+', 29), RED, 'ADS VDD ← 3V3'),
]


# ---------------------------------------------------------------- validation
def node_of(hole):
    row, col = hole
    if row in RAILS:
        return ('rail', row)
    if row in TOP_ROWS:
        return ('top', col)
    if row in BOT_ROWS:
        return ('bot', col)
    raise ValueError(hole)


def validate():
    errs = []
    used = {}
    for ref, p in parts.items():
        for pin, hole in p['pins'].items():
            r, c = hole
            if not (1 <= c <= NCOLS):
                errs.append(f'{ref}.{pin} off board at {hole}')
            if hole in used:
                errs.append(f'hole {r}{c} used by {used[hole]} and {ref}.{pin}')
            used[hole] = f'{ref}.{pin}'
    for a, b, _, lab in jumpers:
        for h in (a, b):
            if h in used:
                errs.append(f'jumper "{lab}" end {h[0]}{h[1]} collides with {used[h]}')
            used[h] = f'jumper {lab}'

    parent = {}

    def find(x):
        parent.setdefault(x, x)
        while parent[x] != x:
            parent[x] = parent[parent[x]]
            x = parent[x]
        return x

    def union(a, b):
        parent[find(a)] = find(b)

    for a, b, _, _ in jumpers:
        union(node_of(a), node_of(b))
    # redundant MP1584 holes are internally the same net
    for p in '1234':
        union(node_of(parts['U1']['pins'][p]), node_of(parts['U1']['pins'][p + 'b']))
    # off-board: J1.1 -- F1.1 (battery+ through the fuse) is not on the board

    t = NETLIST.read_text()
    nets = {}
    for m in re.finditer(r'\(net\s*\(code "\d+"\)\s*\(name "([^"]*)"\)(.*?)\n\t\t\)', t[t.index('(nets'):], re.S):
        nets[m[1]] = re.findall(r'\(ref "([^"]+)"\)\s*\(pin "([^"]+)"\)', m[2])
    if not nets:
        errs.append('no nets parsed from netlist')

    group_net = {}
    net_report = []
    for net, nodes in nets.items():
        groups = set()
        for ref, pin in nodes:
            hole = parts.get(ref, {}).get('pins', {}).get(pin)
            if hole is None:
                if parts.get(ref, {}).get('kind') == 'off':
                    continue
                errs.append(f'{net}: {ref}.{pin} not placed')
                continue
            groups.add(find(node_of(hole)))
        if len(groups) > 1:
            errs.append(f'{net}: OPEN — split across {len(groups)} groups')
        for g in groups:
            if g in group_net and group_net[g] != net:
                errs.append(f'SHORT: {net} and {group_net[g]}')
            group_net[g] = net
        net_report.append((net, len(nodes)))

    # rails must carry the nets they are labelled with
    # (unnamed nets get auto-names that shift with refs, so identify by a member pin)
    net_with = lambda ref, pin: next(n for n, nodes in nets.items() if (ref, pin) in nodes)
    expect = {'T+': '/12vPROT', 'T-': '/GND', 'B+': net_with('U2', '2'), 'B-': '/GND'}
    for rail, want in expect.items():
        got = group_net.get(find(('rail', rail)), '(nothing)')
        if got != want:
            errs.append(f'rail {rail} should carry {want} but carries {got}')

    # unused module pins must be isolated
    netted = {(r, p) for nodes in nets.values() for r, p in nodes}
    for ref in ('U2', 'U3'):
        for pin, hole in parts[ref]['pins'].items():
            if (ref, pin) in netted:
                continue
            g = find(node_of(hole))
            if g in group_net:
                errs.append(f'unused {ref}.{pin} lands on net {group_net[g]}')
            others = [who for h2, who in used.items()
                      if h2[0] not in RAILS and h2 != hole and node_of(h2) == node_of(hole)]
            if others:
                errs.append(f'unused {ref}.{pin} shares strip with {others}')
    return errs, net_report


# ---------------------------------------------------------------- rendering
P = 18                      # px per 0.1"
X0, Y0 = 70, 70
ROW_Y = {'T+': 0, 'T-': 1, **{r: 3 + i for i, r in enumerate(TOP_ROWS)},
         **{r: 10 + i for i, r in enumerate(BOT_ROWS)}, 'B+': 16, 'B-': 17}


def xy(hole):
    r, c = hole
    return X0 + (c - 1) * P, Y0 + ROW_Y[r] * P


def ry(spec):
    """'c-' = half a pitch above row c, 'h+' = half below row h."""
    r, s = spec[:-1], spec[-1]
    return Y0 + ROW_Y[r] * P + (-0.5 if s == '-' else 0.5) * P * 1.6


def render(net_report):
    W = X0 * 2 + (NCOLS - 1) * P
    H = Y0 * 2 + 17 * P + 40
    s = [f'<svg xmlns="http://www.w3.org/2000/svg" viewBox="0 0 {W} {H}" width="{W}" '
         f'font-family="ui-monospace,Menlo,monospace">']
    s.append(f'<rect x="{X0-40}" y="{Y0-40}" width="{(NCOLS-1)*P+80}" height="{17*P+80}" rx="10" fill="#f4f1ea" stroke="#cfc8b8"/>')
    # rails
    for rail, col in (('T+', '#dc2626'), ('T-', '#2563eb'), ('B+', '#dc2626'), ('B-', '#2563eb')):
        y = Y0 + ROW_Y[rail] * P
        s.append(f'<line x1="{X0-10}" x2="{X0+(NCOLS-1)*P+10}" y1="{y + (-P*0.55 if rail in ("T+","B+") else P*0.55)}" '
                 f'y2="{y + (-P*0.55 if rail in ("T+","B+") else P*0.55)}" stroke="{col}" stroke-width="2"/>')
        s.append(f'<text x="{X0-34}" y="{y+4}" font-size="11" fill="{col}">{rail}</text>')
        s.append(f'<text x="{X0+(NCOLS-1)*P+16}" y="{y+4}" font-size="10" fill="{col}">{RAILS[rail]}</text>')
    # channel
    s.append(f'<rect x="{X0-10}" y="{Y0+7.6*P}" width="{(NCOLS-1)*P+20}" height="{1.8*P}" fill="#e7e1d3"/>')
    # holes + labels
    for c in range(1, NCOLS + 1):
        x = X0 + (c - 1) * P
        if c == 1 or c % 5 == 0:
            s.append(f'<text x="{x}" y="{Y0+2.2*P}" font-size="9" text-anchor="middle" fill="#8a8374">{c}</text>')
            s.append(f'<text x="{x}" y="{Y0+15.3*P}" font-size="9" text-anchor="middle" fill="#8a8374">{c}</text>')
        for r in ROW_Y:
            s.append(f'<rect x="{x-3}" y="{Y0+ROW_Y[r]*P-3}" width="6" height="6" fill="#3b3830" opacity=".55"/>')
    for r in TOP_ROWS + BOT_ROWS:
        s.append(f'<text x="{X0-22}" y="{Y0+ROW_Y[r]*P+4}" font-size="10" fill="#8a8374">{r}</text>')

    # modules
    for ref, p in parts.items():
        if p['kind'] != 'module':
            continue
        c0, r0, c1, r1 = p['body']
        x0, x1 = X0 + (c0 - 1) * P, X0 + (c1 - 1) * P
        y0, y1 = ry(r0), ry(r1)
        s.append(f'<rect x="{x0}" y="{y0}" width="{x1-x0}" height="{y1-y0}" rx="4" fill="{p["color"]}" '
                 f'fill-opacity=".18" stroke="{p["color"]}" stroke-width="2"/>')
        ly = Y0 + 8.5 * P + 4 if ref in ('U1', 'U2') else y1 + 14
        if ref == 'J2':
            ly = y1 + 30
        s.append(f'<text x="{(x0+x1)/2}" y="{ly}" font-size="11" font-weight="bold" text-anchor="middle" '
                 f'fill="{p["color"]}">{html.escape(p["label"])}</text>')
        for pin, hole in p['pins'].items():
            x, y = xy(hole)
            nm = p['names'][pin]
            used_pin = nm not in ('—', 'A1', 'A2', 'A3', 'ALRT')
            s.append(f'<rect x="{x-5}" y="{y-5}" width="10" height="10" fill="{p["color"] if used_pin else "#bbb"}"/>')
            if nm != '—':
                up = hole[0] in 'abc' or ref == 'J2'
                ty = y - 8 if up else y + 10
                anchor = 'start' if up else 'end'
                s.append(f'<text x="{x+2}" y="{ty}" font-size="8.5" text-anchor="{anchor}" '
                         f'transform="rotate(-50 {x+2} {ty})" fill="{p["color"]}">{html.escape(nm)}</text>')

    # cable landings
    for ref, p in parts.items():
        if p['kind'] != 'cable':
            continue
        for pin, hole in p['pins'].items():
            x, y = xy(hole)
            s.append(f'<circle cx="{x}" cy="{y}" r="6" fill="none" stroke="{p["color"]}" stroke-width="2.5"/>')
            dx = 14 if hole[0] not in RAILS else -14       # rail landings label to the left, clear of U3
            s.append(f'<path d="M{x},{y} l{dx},-10" stroke="{p["color"]}" stroke-width="2.5" stroke-dasharray="3 2"/>')
            s.append(f'<text x="{x+dx*1.15}" y="{y-12}" font-size="9" text-anchor="{"start" if dx > 0 else "end"}" '
                     f'fill="{p["color"]}">{html.escape(p["names"][pin])}</text>')

    # two-lead parts
    for ref, p in parts.items():
        if p['kind'] != 'lead':
            continue
        (xa, ya), (xb, yb) = xy(p['pins']['1']), xy(p['pins']['2'])
        s.append(f'<line x1="{xa}" y1="{ya}" x2="{xb}" y2="{yb}" stroke="#666" stroke-width="2"/>')
        mx, my = (xa + xb) / 2, (ya + yb) / 2
        if ya == yb:
            s.append(f'<rect x="{mx-P*0.9}" y="{my-5}" width="{P*1.8}" height="10" rx="4" fill="{p["color"]}"/>')
            s.append(f'<text x="{mx}" y="{my-9}" font-size="9" text-anchor="middle" fill="#333">{html.escape(p["label"])}</text>')
        else:
            s.append(f'<rect x="{mx-5}" y="{my-P*0.45}" width="10" height="{P*0.9}" rx="3" fill="{p["color"]}"/>')
            if p['pins']['1'][0] in RAILS:      # rail-to-rail part: label above the board, angled
                ly = Y0 - P * 1.1
                s.append(f'<text x="{mx}" y="{ly}" font-size="9" fill="#333" '
                         f'transform="rotate(-40 {mx} {ly})">{html.escape(p["label"])}</text>')
            else:
                s.append(f'<text x="{mx+9}" y="{my+3}" font-size="9" fill="#333">{html.escape(p["label"])}</text>')
        for h in p['pins'].values():
            x, y = xy(h)
            s.append(f'<circle cx="{x}" cy="{y}" r="3.5" fill="#666"/>')

    # jumpers
    for a, b, col, lab in jumpers:
        (xa, ya), (xb, yb) = xy(a), xy(b)
        if ya == yb:
            path = f'M{xa},{ya} Q{(xa+xb)/2},{ya-P*1.2} {xb},{yb}'
        elif xa == xb:
            path = f'M{xa},{ya} L{xb},{yb}'
        else:
            path = f'M{xa},{ya} C{xa},{(ya+yb)/2} {xb},{(ya+yb)/2} {xb},{yb}'
        s.append(f'<path d="{path}" fill="none" stroke="{col}" stroke-width="3.2" stroke-linecap="round" opacity=".9"><title>{html.escape(lab)}</title></path>')
        for x, y in ((xa, ya), (xb, yb)):
            s.append(f'<circle cx="{x}" cy="{y}" r="3" fill="{col}"/>')

    # bench lead
    x, y = xy(('T+', 1))
    s.append(f'<text x="{x-58}" y="{y-56}" font-size="9" fill="#dc2626">bench + via F1 fuse → T+ @1</text>')
    x, y = xy(('T-', 1))
    s.append(f'<text x="{x-58}" y="{y+18}" font-size="9" fill="#2563eb">bench −</text>')
    s.append('</svg>')
    return '\n'.join(s)


def hole_name(h):
    return f'{h[0]} rail @{h[1]}' if h[0] in RAILS else f'{h[0]}{h[1]}'


def build_table():
    rows = []
    for ref, p in parts.items():
        if p['kind'] in ('module', 'cable'):
            used = [f'{p["names"][k]}={hole_name(h)}' for k, h in p['pins'].items() if p['names'][k] != '—']
            rows.append((ref, p['label'], ', '.join(used)))
        elif p['kind'] == 'lead':
            note = f' — {p["polar"]}' if p.get('polar') else ''
            rows.append((ref, p['label'], f'{hole_name(p["pins"]["1"])} ↔ {hole_name(p["pins"]["2"])}{note}'))
    jr = [(hole_name(a), hole_name(b), lab) for a, b, _, lab in jumpers]
    return rows, jr


def main():
    errs, net_report = validate()
    if errs:
        print('LAYOUT ERRORS:')
        for e in errs:
            print('  ', e)
        sys.exit(1)
    print(f'OK: {len(net_report)} nets, no opens, no shorts, unused pins isolated')
    rows, jr = build_table()
    svg = render(net_report)
    td = lambda cells: '<tr>' + ''.join(f'<td>{html.escape(c)}</td>' for c in cells) + '</tr>'
    OUT.write_text(f'''<!doctype html><meta charset="utf-8"><title>Irin breadboard</title>
<style>body{{font:14px -apple-system,system-ui,sans-serif;margin:24px;background:#fff;color:#222}}
table{{border-collapse:collapse;margin:8px 0 24px}}td,th{{border:1px solid #ddd;padding:4px 8px;text-align:left;vertical-align:top}}
th{{background:#f4f1ea}} .wrap{{overflow-x:auto}} code{{background:#f4f1ea;padding:1px 4px}}</style>
<h2>Irin 12V battery monitor — breadboard (400-point, 30 columns)</h2>
<p>Generated by <code>make_breadboard.py</code> and validated against <code>irin.net</code>:
every net connected, no shorts, unused module pins isolated. Hover a jumper for its purpose.</p>
<div class="wrap">{svg}</div>
<h3>Parts</h3><table><tr><th>Ref</th><th>Part</th><th>Holes</th></tr>{''.join(td(r) for r in rows)}</table>
<h3>Jumpers</h3><table><tr><th>From</th><th>To</th><th>Purpose</th></tr>{''.join(td(r) for r in jr)}</table>
''')
    print('wrote', OUT)


if __name__ == '__main__':
    main()

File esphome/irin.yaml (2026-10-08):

# Irin — battery monitor for Home Assistant (ESPHome)
#
# This file is the prototype instance, "Uncharted 12V": the 12V accessory battery
# of a 2027 Subaru Uncharted GT. Change device_name / friendly_name for your own.
#
# Battery: flooded lead-acid (Pb), 50 Ah, stock Uncharted accessory battery (NOT AGM)
# Board:  01Space ESP32-C3-0.42LCD
# ADC:    ADS1115 @ 0x48, A0 via 47k/10k divider (5.72:1 measured), 2 nF mica across R2
# Temp:   DHT22 on GPIO3, remote-mounted outside the enclosure via J2 (<=1 m cable)
# Display: SSD1306 72x40 @ 0x3C
#
# See CLAUDE.md for design rationale and README.md "Customizing" for other
# chemistries and 24/48 V systems. Bench-verified 2026-10-06: I2C pin order,
# OLED, ADS1115 two-point calibration, rest gate.
#
# SPDX-License-Identifier: MIT

substitutions:
  # Irin firmware version (semver). Bump it in the same commit as any change to
  # this file that alters behavior, then tag the commit vX.Y.Z. See README
  # "Versioning". Shown in HA's device page and as the Firmware sensor.
  irin_version: "0.3.0"

  # Instance names. Entity IDs in HA derive from friendly_name; changing either
  # on a running install creates new entities and orphans the old history.
  device_name: uncharted-batt
  friendly_name: "Uncharted 12V"
  # Fallback WiFi network name (raised 90 s after home WiFi is lost; used to
  # enter a new WiFi password from a phone). Deliberately doesn't name the
  # vehicle, since it broadcasts wherever the car is parked. "Sunny" is the
  # car's name: she runs on sunlight.
  ap_ssid: "irin-Sunny"

  # --- Tunables -------------------------------------------------------------
  # Charging detection (the vehicle DC-DC on the Uncharted), with hysteresis so
  # it can't chatter at the boundary.
  charge_on_threshold: "12.90"      # V — above this, converter is running
  charge_off_threshold: "12.80"     # V — below this, resting
  # Valid for flooded Pb as-is: a healthy full flooded battery rests ~12.6-12.7 V,
  # so anything above 12.80 still means "not resting yet".

  # Rest gate for SOC. Both conditions must hold.
  rest_required_sec: "1800"       # 30 min below charge_off_threshold
  stable_required_sec: "900"      # 15 min of settled voltage
  slope_tolerance: "0.005"        # V drift allowed per 5 min window (= 1 mV/min)

  # Temperature coefficient of flooded lead-acid OPEN-CIRCUIT voltage, whole
  # 12 V battery: ~0.7 mV/degC/cell x 6 (from the hydrometer correction,
  # 0.004 SG per 10 degF). NOT the 3-5 mV/degC/cell charger setpoint
  # compensation, which would over-correct cold readings and suppress the 50%
  # alert in winter. The DHT22 reads air near the battery, not case temperature,
  # so this is a seasonal correction only.
  temp_coeff: "0.004"             # V per degC

  # OLED stays lit this long after boot, a BOOT-button press, or the end of a
  # charging run. Blanked otherwise to limit burn-in of the static layout.
  display_wake_ms: "120000"

  # Away report. While Home Assistant is unreachable (car away from home WiFi,
  # or HA down), the device keeps a summary of the battery: lowest voltage,
  # lowest SOC, time below the alert SOC, charging. It is published on
  # reconnect. Gaps shorter than away_min_sec (HA restarts, WiFi blips, OTA)
  # are discarded and leave the previous report in place.
  soc_alert_pct: "50"             # SOC alert level; match the HA automation
  away_min_sec: "1800"            # 30 min

  # Resting (open-circuit) voltage -> SOC at 25 degC, ascending, same length.
  # Flooded lead-acid (Pb), 12 V. These are RESTED voltages, not charging
  # voltages. NOT an AGM table: AGM rests 0.10-0.15 V higher, so an AGM table
  # would read this battery high and fire the 50% alert late. Capacity only sets
  # how fast a given drain moves SOC; it does not change this lookup.
  # Other chemistries and 24/48 V systems: see README "Customizing".
  soc_table_v:   "11.60, 11.75, 11.90, 12.02, 12.12, 12.22, 12.30, 12.38, 12.48, 12.58, 12.70"
  soc_table_pct: "    0,    10,    20,    30,    40,    50,    60,    70,    80,    90,   100"

esphome:
  name: ${device_name}
  friendly_name: ${friendly_name}
  # HA's device page shows this next to the ESPHome version. ESPHome requires
  # the "author.project" form.
  project:
    name: "mglauser.irin"
    version: "${irin_version}"
  on_boot:
    # Republish the last valid resting SOC so HA doesn't show "unknown" for
    # the hours or days until the next rest window.
    priority: -100
    then:
      - lambda: |-
          if (id(soc_valid)) id(batt_soc).publish_state(id(last_soc));
      - script.execute: publish_away_report
      - component.update: fw_version

esp32:
  board: esp32-c3-devkitm-1
  variant: esp32c3
  framework:
    type: esp-idf

logger:
  level: INFO
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

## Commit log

2026-10-06 Initial commit: Uncharted 12V battery monitor
    ESP32-C3 + ADS1115 monitor for a 12V flooded lead-acid battery, reporting to
    Home Assistant via ESPHome. Bench-verified 2026-10-06:
    - 47k/10k divider (2 nF mica), two-point calibrated; analog ground returned
    to the ADS1115 GND pin at a single point
    - Voltage published ungated; SOC gated on a 30 min rest + dV/dt stability
    test, temperature-corrected (remote DHT22 via J2)
    - Charging detection with 12.8/12.9 V hysteresis; time-since-charging
    diagnostic
    - OLED blanks after 2 min (BOOT button wakes); no reboot on HA outage
    - KiCad schematic, validated breadboard layout generator, HA dashboard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
    [uncharted-battery-monitor.kicad_pcb, uncharted-battery-monitor.kicad_sch]
2026-10-06 Add licenses, rewrite README for general use, move SOC table to substitutions
    - LICENSE: MIT for firmware, HA configs, scripts and docs
    - hardware/LICENSE: CERN-OHL-P-2.0 (official CERN text) for the KiCad design;
    hardware/breadboard/ stays MIT (SPDX header on the generator)
    - README: project overview, build/calibrate/HA install steps, and
    customization for flooded, AGM, LiFePO4 and sodium-ion chemistries and for
    24V/48V systems (divider, buck, TVS and fuse ratings, firmware scaling)
    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
2026-10-06 Rename project to Irin
    Irin (Aramaic ʿirin, "watchers", "the wakeful ones") from the Book of
    Enoch; the name's root is documented in README.md and CLAUDE.md.
    - KiCad project hardware/irin.*, footprint library Uncharted -> Irin;
    ERC unchanged, regenerated netlist equivalent, preview.pdf refreshed
    - Firmware config esphome/irin.yaml, dashboard ha_config/dashboard.yaml
    - Breadboard generator points at irin.net; regenerated, validates OK
    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
    [irin.kicad_pcb, irin.kicad_sch]
2026-10-06 Add away report: battery summary while Home Assistant is unreachable
    While HA is unreachable (car away from home WiFi, HA down), the device
    tracks duration, min voltage, min gated SOC, time below the alert SOC,
    charging time and charge events, and publishes them on reconnect. Gaps
    shorter than away_min_sec (30 min) are ignored and keep the last report.
    State survives the hourly no-WiFi reboot; flash writes are batched every
    5 min while away and none occur at home. Dashboard gets a "Last time
    away" section. Compiled; not yet bench-tested.
    [irin.yaml]
2026-10-06 Correct reboot comments: no-WiFi reboot is inert with a fallback AP
    ESPHome skips wifi reboot_timeout when ap: is configured, so the device
    never reboots hourly while away. Comments only; no behavior change.
    [irin.yaml]
2026-10-07 Document the fallback WiFi network: rescue procedure, power cost, opt-out
    Measured on the bench: ~40 mA at 12 V out of WiFi range with the fallback
    AP up, vs ~10 mA on WiFi. README explains the password-rescue procedure,
    that portal-saved credentials revert on the next changed install, the
    planned two-password method, and how to remove the AP with its trade-offs.
    CLAUDE.md power budget records the measurement.
2026-10-07 Add password-protected status page (web_server v3, local)
    For checking the battery from a phone in the car: join the fallback AP
    and open http://192.168.4.1; also on the home LAN. Entities grouped as
    Battery / Last time away / Diagnostics. The web server's handler is
    registered before the captive portal's, so it gets "/" while the portal
    keeps answering the phone's login probe. Compiled; flash 54%.
2026-10-07 Status page: WiFi Setup link, shown only while the fallback AP is up
    Serves ESPHome's stock v3 page script via js_include with a small addition
    (esphome/www/wifi_link.js) that inserts a WiFi Setup link above OTA Update when
    the captive portal answers /config.json. local: true ignores js_include, hence
    the generator (esphome/www/build_www.py); its output is not committed.
2026-10-07 Readable uptime; rest gate credits only observed rest intervals
    Uptime is now the uptime text_sensor ('3h 12m', '2d 5h 40m') instead of raw
    seconds. HA sees a new entity (text_sensor unique ID); the old one was removed
    and the new one renamed to sensor.uncharted_12v_uptime.
    Rest gate: the first 5-min tick below the charge-off threshold (or after boot)
    credited a full 300 s, so the gate could pass after 25 min. A bench step from
    13.56 V to 10.72 V passed at 26 min. Now rest is credited only when the
    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
2026-10-07 Firmware versioning: Irin 0.3.0
    irin_version substitution feeds esphome: project: (mglauser.irin, shown on
    HA's device page) and a Firmware diagnostic text sensor with the Irin and
    ESPHome versions and build time. README gets a Versioning section (bump rules,
    tagging, changelog); CLAUDE.md gets the standing check-and-bump instruction.
2026-10-08 Docs: drop unmeasured 430 mA draw; PCB grounding, mechanics, DHT22 inside
    - Vehicle parasitic draw was never measured: remove the 430 mA figure and
    everything derived from it. Use the observed ~0.1 V/day resting drop,
    labelled as an estimate (~5 days to 50%), until Irin logs a multi-day sit.
    - P6KE18A specs and orientation (banded end to 12vPROT).
    - Single-point analog ground applies to wired builds; on the PCB R2/C1 go
    straight to the solid GND plane.
    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
2026-10-08 Hardware: conventional schematic symbols; PCB outline, placement, GND plane, routing
    Schematic (netlist unchanged):
    - ANSI resistors, two-plate caps, TVS with cathode bar, fuse, battery (J1)
    - Detailed ESP32-C3, ADS1115 and DHT22 symbols; U2 3V3 top / GND bottom,
    U1 outputs on the right
    PCB:
    - Board outline 78.5 x 69 mm, four M3 mounting holes inset 3.5 mm
    - Parts re-placed, C3 at the buck input, divider beside the ADS1115
    - B.Cu GND plane with thermal reliefs; "Pwr" net class (0.4 mm) for 12vPROT
    - Fully routed: DRC 0 violations, 0 unconnected, 0 schematic parity issues
    Regenerated preview.pdf and irin.net.
    [irin.kicad_pcb, irin.kicad_sch]
2026-10-09 Hardware rev B: swap buck and ADC sides, reroute, antenna keepout
    - U1 (MP1584) and U3 (ADS1115) swapped so each sits beside the U2 pins it
    serves; input parts (J1, D1, C3, C2) moved to the right/top, 12 V now a
    straight drop to U1. All routing on F.Cu; B.Cu is an unbroken GND plane
    apart from a rule-area keepout under U2's antenna end. No vias.
    DRC 0 / unconnected 0 / parity clean.
    - Schematic: F1 is the inline harness fuse (excluded from board, kept in
    BOM); BT1 (vehicle battery, off-board) added inside a dashed
    "OFF-BOARD (vehicle harness)" box. J1 redrawn as a 2-pin connector.
    J2 and divider notes updated (DHT22 inside for now; PCB divider ground
    goes straight to the plan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
    [irin.kicad_pcb, irin.kicad_sch]
2026-10-09 Hardware rev B: screw-terminal J1, full silkscreen, D1 standard
    - J1: 5.08 mm 2-pin screw terminal (Phoenix MKDS 1,5-2-5.08 footprint,
    KF301-2P fits) at the top edge, wire openings facing out; replaces the
    2.54 mm header, which neither takes 18 AWG nor survives vibration.
    - Silkscreen for kit builders: part values on every part, J1 +/-, J2
    VCC/DATA/GND, U1 IN/OUT, U2 used pins and USB-C end, U3 pin names,
    "Irin - by AI7MG - rev B". Values shortened to fit (C1, J2, U3, J1).
    Mounting-hole references hidden.
    - D1 (P6KE18A) fitted as standard: it also acts as the reverse-polarity
    crowbar (reversed hookup forward-biases D1 and blows F1). Schematic
    notes, CLAUDE.md, PARTS.md and READ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
    [irin.kicad_pcb, irin.kicad_sch]
2026-10-10 HA config: fix the SOC staleness condition, correct chemistry
    The primary SOC-low alert could never have fired. Both automations gated on
    sensor.uncharted_12v_soc_age, which does not exist: the firmware publishes
    "SOC Last Updated" as a timestamp, not an age in hours. A numeric_state
    condition against a missing entity evaluates false, so the alert was silently
    suppressed with no error anywhere — indistinguishable from a healthy battery.
    Replaced with a template condition on the timestamp in both files.
    Core alerts:
    - flooded sulfation, not AGM cycle life, as the reason for the 50% threshold
    - drop "roughly 3 days to flat" from the message; that was the deleted,
    never-measured 430 mA fig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
2026-10-10 Hardware rev B: plotted gerbers, verified at 1:1
    Gerber set for rev B (RS-274X, 2 layers, plus the .gbrjob). Printed at 1:1 and
    laid against the real parts: the ESP32-C3 module, ADS1115 and MP1584EN
    footprints all line up.
    Generated output, committed deliberately so the repo is self-contained for
    anyone fabbing rev B without opening KiCad.
    The kicad_pcb change is only the plot dialog's drillshape setting, saved when
    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
    [irin-B_Cu.gbr, irin-B_Mask.gbr, irin-B_Paste.gbr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]
2026-10-10 Hardware rev B: Excellon drill files, PTH and NPTH separate
    Completes the fab package for rev B. Absolute origin, metric, decimal, to
    match the gerbers' (useauxorigin no).
    51 plated holes (0.80-1.30 mm) and 4 unplated 3.20 mm M3 mounting holes.
    Smallest hole is 0.80 mm, well clear of any fab's minimum on 2 layers.
    PTH and NPTH are deliberately in separate files rather than merged. A merged
    file marks the non-plated holes only with Gerber X2 attributes, which some
    fab workflows ignore and then plate the mounting holes; a reported PCBWay
    upload rejection was also resolved by supplying PTH and NPTH separately.
    Separate files state the intent unambiguously, and PCBWay is the intended
    house for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
    [irin-NPTH.drl, irin-PTH.drl]
2026-10-10 Ignore presentation/ — talk slides, large binaries
2026-10-20 Fix the U1 footprint; rev B's is 0.1in too narrow
    The first rev B board was populated 2026-10-20 and the MP1584EN would not
    fit U1. Built anyway by clipping one leg off each negative end and mounting
    the module from the underside -- board #1 is live and reading 12.55 V and
    14.40 V dead-on, with the breadboard's divider resistors transplanted so
    the existing calibration carries over unchanged.
    The old footprint's across-module spacing was ruler-measured at +/-0.5mm and
    came out 0.1in too narrow overall: inner holes 0.2in apart where the part
    needs 0.3in. Caliper measurement puts the four holes along an edge at
    0.0 / 0.1 / 0.4 / 0.5 in, and the module outline at 0.66 x 0.86 in
    (16.76 x 21.84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
2026-10-20 Enclosure: FreeCAD source, STEP/STL/3MF and previews
    Printed in PETG on a P1S and fitted 2026-10-20: the first rev B board is
    mounted in the box on heat-set inserts, with one cable entry for the 12 V
    leads as designed.
    irin_box.FCMacro is the parametric source; the STEP, STL and 3MF are
    generated from it. Shipped rather than gitignored because they are the
    deliverable for anyone else building an Irin -- hardware/ is CERN-OHL-P.
2026-10-21 Fix mirrored pad polarity in the U1 footprint
    Second defect in the same footprint, found while reviewing the corrected
    one: the '-' nets were on the left, which is backwards for a top-mounted
    module. VIN+ and VOUT+ now sit on the left as the footprint is drawn,
    viewed from the top, with the rectangular pads marking them.
    On rev B board #1 the two defects cancelled. The workaround for the
    too-narrow holes was to mount the module from the underside, which mirrors
    the rows back -- which is why a board built on a wrong footprint runs
    correctly, and why this was not caught electrically. A rev C board with U1
    mounted normally on top would have fed IN+ into IN-.
    Both footprint descriptions and th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
2026-10-21 Board: mirror U1 pad polarity; silkscreen rework
    The rev B board put + on the right at U1, but the real MP1584EN module has
    - on the right. Update Footprints from Library pulled in the corrected
    10.16mm hole spacing but predated the polarity fix, so the board kept the
    old arrangement.
    Mirrored U1's eight pad x-coordinates in place, which moves /12vPROT and
    Net-(U1-OUT+) to the left and /GND to the right while leaving pad numbers,
    nets, shapes and UUIDs alone. Verified against the library: all 8 pads now
    match on position, shape, size and drill. The F.Fab VIN/VOUT labels in the
    board instance were still reading the old way and are swapped to match.
    Also includes the owner's silkscreen rewor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
2026-10-21 Hardware rev C: re-plotted gerbers and drill files
    Re-plotted from the rev C board: U1 on the corrected footprint with
    mirrored polarity, U3 moved clear of the DHT22, reference designators
    moved out from under the part bodies, and the silkscreen revision bumped
    to rev C.
    Plotted with KiCad 10.0.5, the same version that produced the rev B set.
    Gerbers use KiCad extensions (--no-protel-ext; KiCad 10 now defaults to
    Protel), and the drill export keeps PTH and NPTH in separate Excellon
    files, which is what PCBWay wanted for rev B. Gerber and drill origins are
    both absolute and consistent.
    Verified against rev B before committing:
    - Board outline unchanged at 78.50 x 69.00 mm
    - NPTH mounting ho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
